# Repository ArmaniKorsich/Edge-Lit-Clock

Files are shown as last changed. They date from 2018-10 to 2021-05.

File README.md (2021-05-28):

# Edge Lit Clock

An Atmega328p powered clock using acryllic panels and ws2812b addressable LEDs as displays.
#
Device View
Front Render

## CAD

All drawings created in Inventor 2016.

The clock consists of 5 seperate displays chained together, with:
* 3
* 10
* 6
* 10
* 6*

panels each. Each panel has a number from 0-9 etched in the following order:  
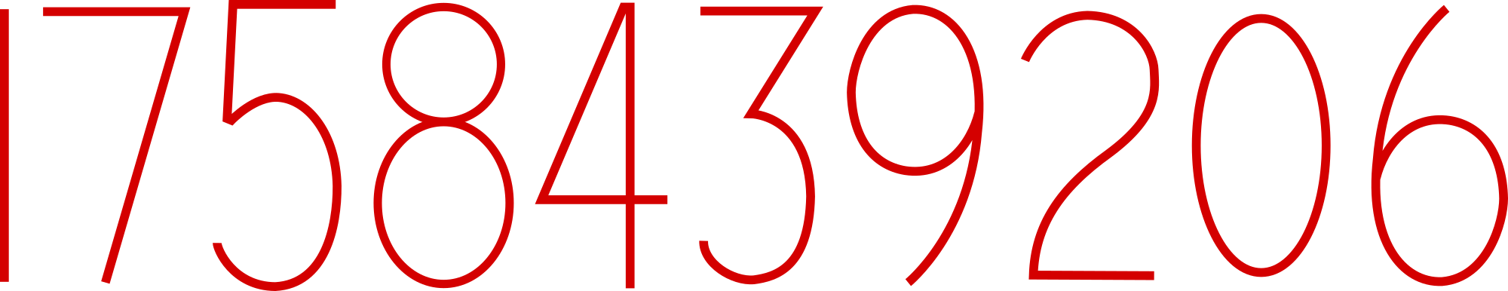
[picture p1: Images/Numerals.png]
Numerals


The off order resembles the old Nixie tube number ordering meant to maximize visiblity of all the digits.

\* *The last display has various symbols instead:*  
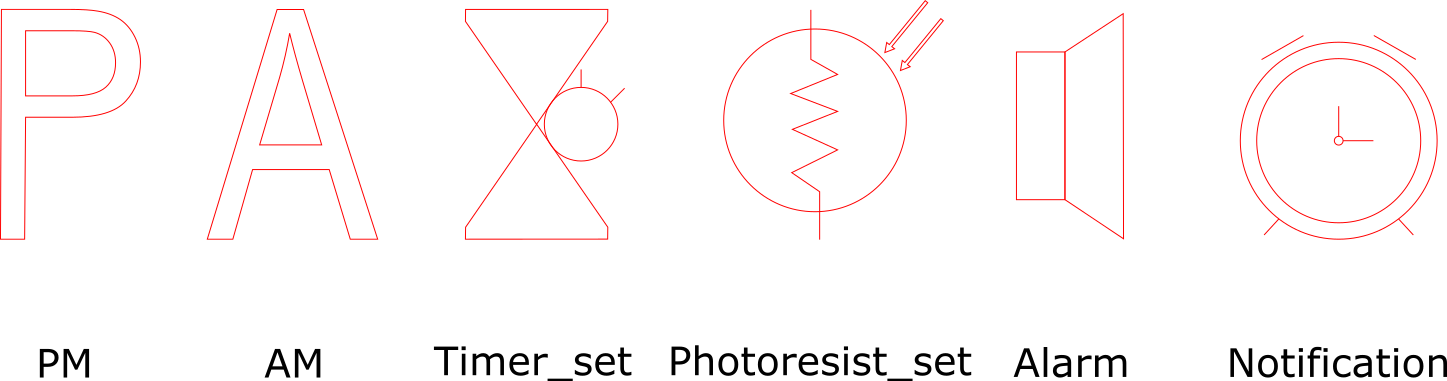
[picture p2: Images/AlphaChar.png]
alpha Symbols


## Electronics

The Atmega328p drives the WS2812B leds using the eLite and FastLED libraries.

The Atmega328p reads time from a DS32321 RTC.  

To protect time information against power outages, I selected a DS3231 which accepts backup battery voltage on PIN14 in the event that VCC cuts out.

All circuit boards were constructed on 2 layer PCBs.
The circuit boards were manufactured by JLCPCB and designed using Autodesk Eagle.

Circuit Board
LED Board

### Input

The device takes 9-40VDC input with at least 2A current capacity. The LM2575-5V buck converter transforms the input to 5V with a 3A limit.

The average current draw of the Edge Lit CLock is ~350 mA with an average of 16 WS2812B activated at any moment.

### Operation

To turn the device on, set the 'POWERTOGGLE' piano switch on the bottom right of the PCB to the 'DOWN' position.

To turn the alarm on, set the 'ALARMTOGGLE' piano switch to the 'DOWN' position.

The three potentiometers on the device control the RED, GREEN, and BLUE color channels of the LEDs.

Pressing the Photoresist_Set button will toggle tracking ambient brightness. When set, the device will lower the brightness of its LEDs to 20% in a fully dark room.

### Setting a Timer

To set a timer, press the TIMER+ or TIMER- button until the device displays the appropriate countdown time.

To start the timer, pres the TIMER_SET button. The device will begin counting down from the set time.

For countdowns over 30 minutes, the device will display hours on the 2 left displays, and minutes on the 2 right displays.

When the countdown reaches <30 minutes, the device will display minutes on the 2 left displays, and seconds on the 2 right displays.

When the countdown reaches 0 seconds, a buzzer will beep.

To disable the buzzing, press the SNOOZE button or restart the device.

## Schematics

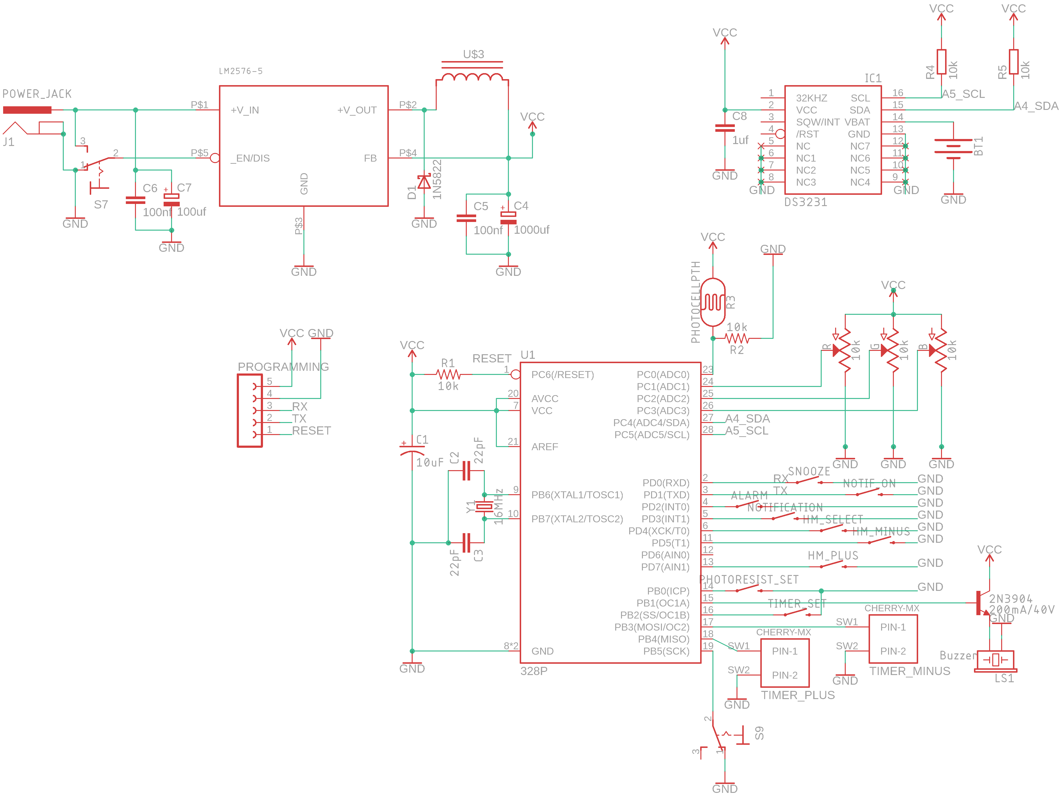
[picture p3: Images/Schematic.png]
Front Render


## Source

This project takes advantage of Arduino's public library system, using 
stdio, FastLED ResponsiveAnalaogRead, EEPROM, Wire, RTCLib
and the provided eLite library for controlling the displays.

ResponsiveAnalogRead: Provides fast and mathematically continuous input values. Minimizes noise in low-cost potentiometers.

stdio: Optional, provides useful debugging information in Arduino IDE.

FastLED: A solution to controlling a large quantity of LEDs rapidly and arbitrarily.

RTClib: Interfaces with the DS3231 Real Time Clock, functions for timekeeping.  

## eLite Library

The eLite library represents the bulk of the content of this project, the clock and physical shape of the project are an example applying this library as my entry to Eisenhower Senior High School's 'Yearly Engineering and Innovation Design Scholarship.'    

`uint8_t defineChain(uint8_t numDisplays,...);`. 
> Inputs(NumDisplays): Number of chained displays in the system.    
> return(chainLength): returns the number of displays in the system.

`void defineLedPerPanel(uint8_t led,...);`. 
> Inputs(led): How many displays there are  
> Inputs(,...): The number of leds per panel in a display, seperated by commas.  
> Tells the system how many LEDs each display has. Useful with physically large plexiglass panels that need more lighting.  
> For a system with 5 displays and 2 leds per panel on each display:  
`void defineLedPerPanel(5, 2, 2, 2, 2, 2)`. 

`void setStandardOrder(uint8_t displayToConfigure);`. 
> inputs(displayToConfigure): Which display to configure. 
> Resets the numercal order of panels in a given display to 0, 1, 2, ... , n. 

`void redefinePanelOrder(uint8_t displayToConfigure, uint8_t quantityPanels,...);`. 
> Inputs(displayToConfigure): Which display to configure   
> Inputs(QuantityPanels): Quantity of panels in display 'DisplayToConfigure'   
> Inputs(,...): The custom order of panels in the display, expects 'QuantityPanels' items, seperated by commas.  

`void drawPanel(uint8_t r, uint8_t g, uint8_t b, uint8_t displayCount, int panelToDraw);`. 
> Inputs(R, G, B): 8-bit integer (0-255), sets the primary color of the displays.     
> Inputs(displayCount): Which display to draw to.  
> Inputs(panelToDraw): The panel to activate in color ##RRGGBB   

`void drawChain(uint8_t r, uint8_t g, uint8_t b, uint8_t lengthOfChain,...);`. 
> Inputs(R, G< B): 8-bit integer (0-255), sets the primary color of the displays.  
> Inputs(lengthOfChain): Number of displays to activate in the chain (0-indexed).  
> inputs(,...): The panel number to activate in each display, seperated by commas.   

`void cycleDisplays(int delayTime, int acceleration, bool direc, uint8_t r, uint8_t g, uint8_t b, uint8_t qtyToCycle,...);`. 
> Inputs(delayTime): Pause between advancing the panels (mS).  
> Inputs(acceleration): Time to decrese delayTime by after each iteration. (mS).  
> Inputs(direc): Cycles forwards (1) or backwards (0).   
> Inputs(R, G, B): 8-bit integer (0-255), sets the primary color of the displays.   
> Inputs(qtyToCycle): Number of displays in the chain to cycle through.   
> Inputs(,...): The index of the displays you wish to cycle through.  
> In a chain of 5 displays, if we wish to cycle the 1st, 3rd, and 4th display:  
`void cycleDisplays(delay, acceleration, forward, R, G, B, 3, 0, 2, 3)`.

`void clearDisplay(uint8_t displayToClear);`
> Inputs(displayToClear): Which display to clear, all panels will be deactivated.  

`void clearChain();`
> Turns off all LEDs in the system, clears all displays.

`uint8_t setChainBrightness(uint8_t brightness);`
> Inputs(brightness): 8-bit integer (0-255), sets the overall opacity (brightness) of the LEDs in FastLED.
> return(brightnessLevel): returns the brightness of the LEDs.

`void randomizeDisplays(int delayTime, int acceleration, int iterations, uint8_t r, uint8_t g, uint8_t b, uint8_t qtyToRandomize, ...);`
> Inputs(delayTime): Pause between iterations in milliseconds (mS).    
> Inputs(acceleration): Time to decrease delayTime by after each iteration. (mS).   
> Inputs(iterations): How many times to activate a random panel on the given displays.    
> Inputs(R, G, B): 8-bit integer (0-255), sets the primary color of the displays.   
> Inputs(qtyToRandomize): Number of displays in the chain to randomize.  
> Inputs(,...): The index of the displays you wish to randomize.  
> If iterations is 1, delay and acceleration aren't important, as the given displays will simply output a random panel. Otherwise, this function provides a simple animation to your chain.

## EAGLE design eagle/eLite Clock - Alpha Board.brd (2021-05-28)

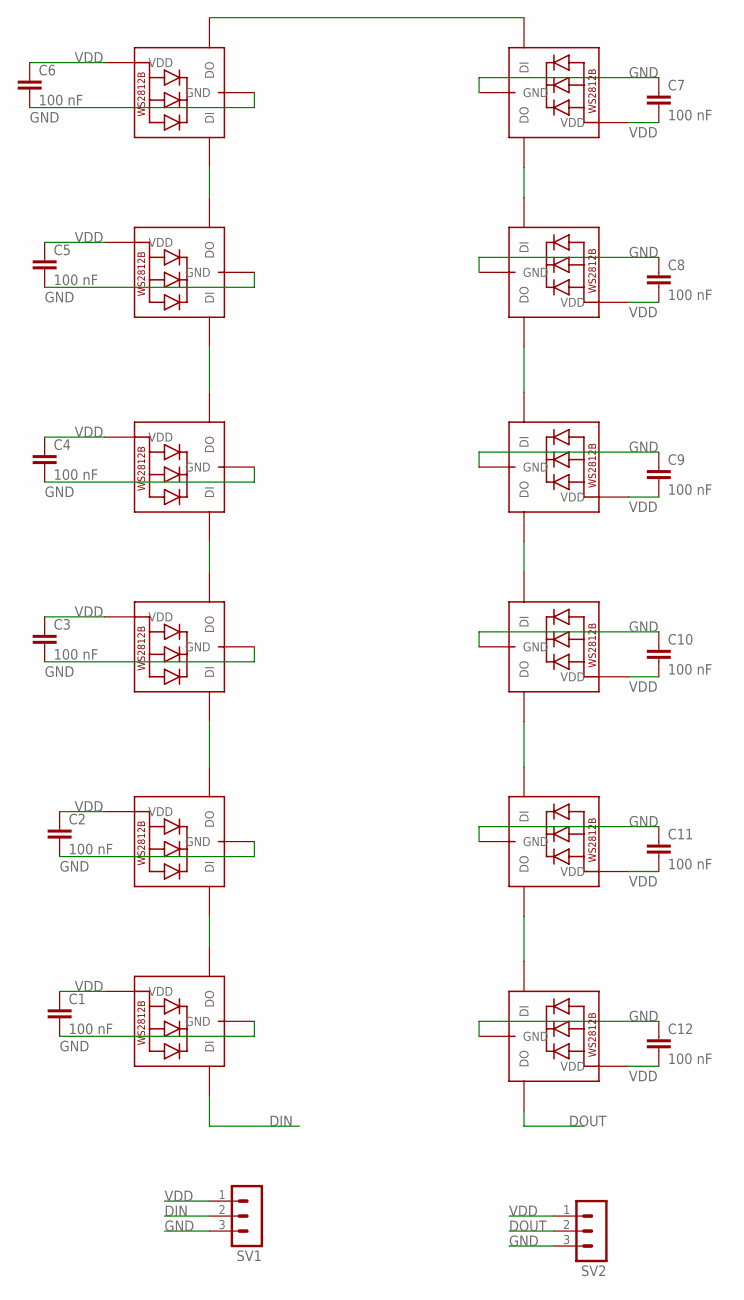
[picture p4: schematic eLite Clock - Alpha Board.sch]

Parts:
C1, C2, C3, C4, C5, C6, C7, C8, C9, C10, C11, C12: 100 nF; C025-025X050
LED1, LED2, LED3, LED4, LED5, LED6, LED7, LED8, LED9, LED10, LED11, LED12: WS2812B_5050W; WS2812B-WIDE
SV1, SV2: MA03-1

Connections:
DIN: LED1.4-DIN (DI), SV1.2
DOUT: LED12.2-DOUT (DO), SV2.2
GND: C1.2, C2.2, C3.2, C4.2, C5.2, C6.2, C7.1, C8.1, C9.1, C10.1, C11.1, C12.1, LED1.3-GND (GND), LED2.3-GND (GND), LED3.3-GND (GND), LED4.3-GND (GND), LED5.3-GND (GND), LED6.3-GND (GND), LED7.3-GND (GND), LED8.3-GND (GND), LED9.3-GND (GND), LED10.3-GND (GND), LED11.3-GND (GND), LED12.3-GND (GND), SV1.3, SV2.3
unnamed: LED1.2-DOUT (DO), LED2.4-DIN (DI)
unnamed: LED2.2-DOUT (DO), LED3.4-DIN (DI)
unnamed: LED3.2-DOUT (DO), LED4.4-DIN (DI)
unnamed: LED4.2-DOUT (DO), LED5.4-DIN (DI)
unnamed: LED5.2-DOUT (DO), LED6.4-DIN (DI)
unnamed: LED6.2-DOUT (DO), LED7.4-DIN (DI)
unnamed: LED7.2-DOUT (DO), LED8.4-DIN (DI)
unnamed: LED8.2-DOUT (DO), LED9.4-DIN (DI)
unnamed: LED9.2-DOUT (DO), LED10.4-DIN (DI)
unnamed: LED10.2-DOUT (DO), LED11.4-DIN (DI)
unnamed: LED11.2-DOUT (DO), LED12.4-DIN (DI)
VDD: C1.1, C2.1, C3.1, C4.1, C5.1, C6.1, C7.2, C8.2, C9.2, C10.2, C11.2, C12.2, LED1.1-VDD (VDD), LED2.1-VDD (VDD), LED3.1-VDD (VDD), LED4.1-VDD (VDD), LED5.1-VDD (VDD), LED6.1-VDD (VDD), LED7.1-VDD (VDD), LED8.1-VDD (VDD), LED9.1-VDD (VDD), LED10.1-VDD (VDD), LED11.1-VDD (VDD), LED12.1-VDD (VDD), SV1.1, SV2.1

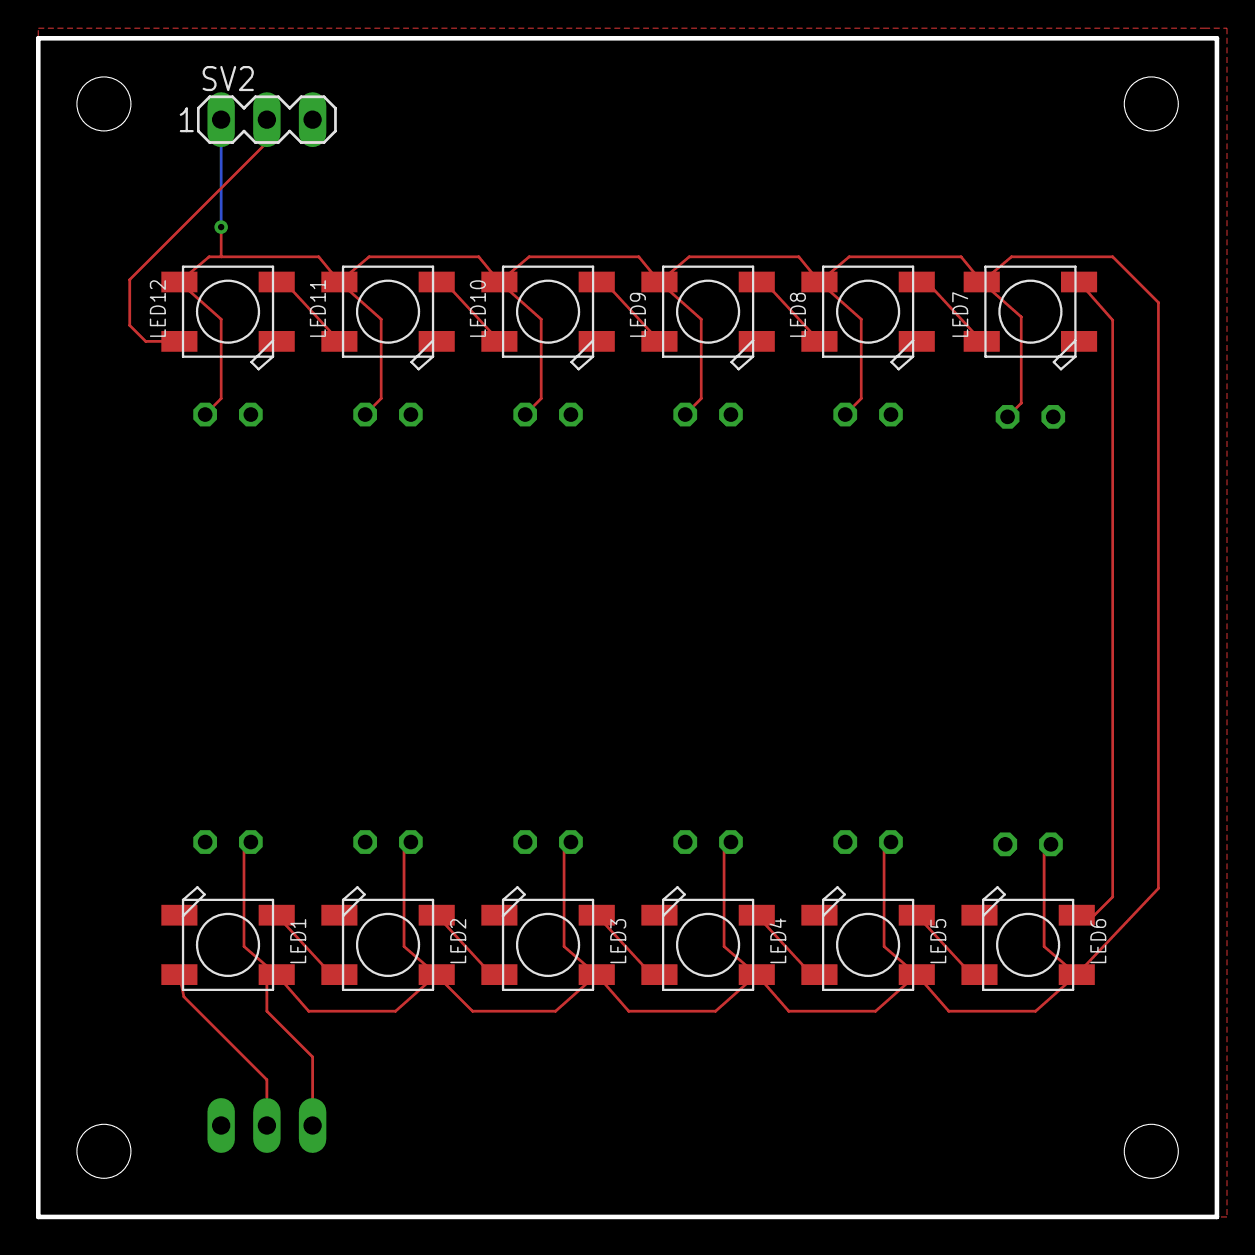
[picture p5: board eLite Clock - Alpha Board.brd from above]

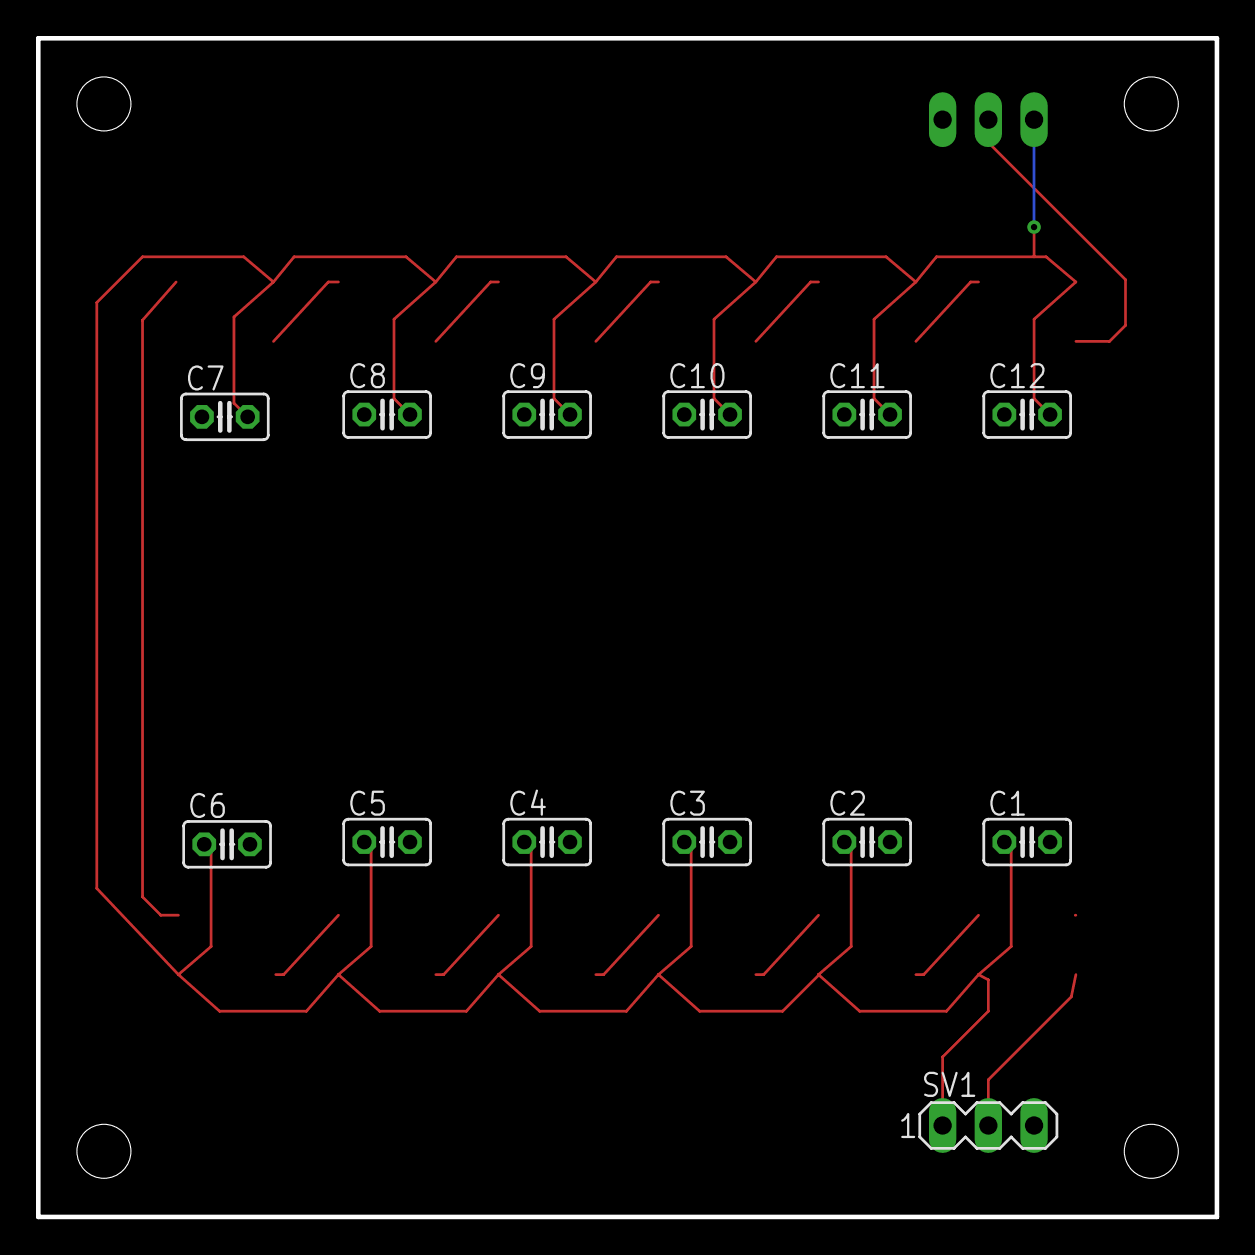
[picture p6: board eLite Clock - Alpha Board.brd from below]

Board: 2 copper layers, 65.5 x 65.5 mm, 26 parts (13 on the bottom side), 15 nets.

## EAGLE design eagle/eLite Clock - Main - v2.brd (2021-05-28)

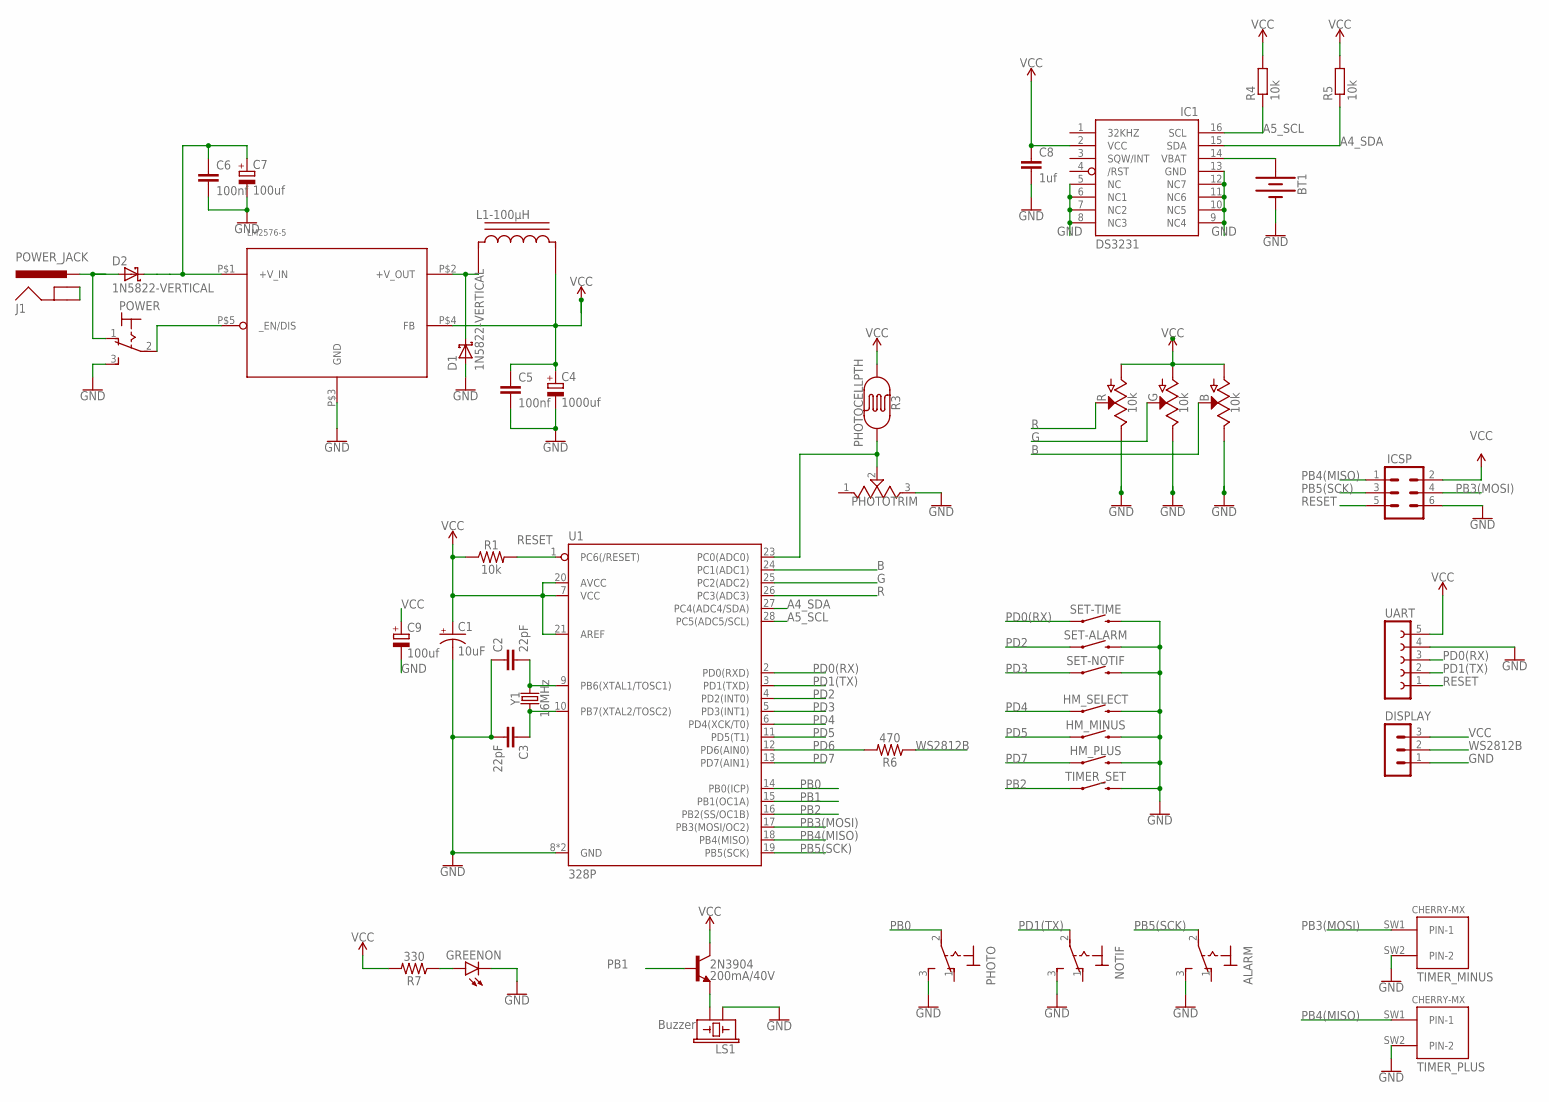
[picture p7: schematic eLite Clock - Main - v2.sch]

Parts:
2N3904: 200mA/40V; TO-92
ALARM: 320-916
B: 10k; SINGLE_GANK_POTENTIOMETER
BT1: BATTERY-20MM_PTH; BATTCOM_20MM_PTH
C1: 10uF; CPOL-RADIAL-2.5MM-5MM
C2, C3: 22pF; CAP-PTH-2.54
C4: 1000uf; E5-13
C5, C6: 100nf; C025-025X050
C7: 100uf; E2,5-5
C8: 1uf; C025-025X050
C9: 100uf; E3,5-10
D1, D2: 1N5822-VERTICAL; DIODE-VERTICAL
DISPLAY: MA03-1
G: 10k; SINGLE_GANK_POTENTIOMETER
GREENON: LED5MM
HM_MINUS: MOMENTARY-SWITCH-SPST-PTH-6.0MM; TACTILE_SWITCH_PTH_6.0MM
HM_PLUS: MOMENTARY-SWITCH-SPST-PTH-6.0MM; TACTILE_SWITCH_PTH_6.0MM
HM_SELECT: MOMENTARY-SWITCH-SPST-PTH-6.0MM; TACTILE_SWITCH_PTH_6.0MM
IC1: DS3231/SO; SO16W
ICSP: MA03-2
J1: POWER_JACK; POWER_JACK_PTH
L1-100µH: T37_INDUCTOR
LM2576-5: LM2576-T05A; TO-220-5_IN-LINE
LS1: Buzzer; BUZZER-12MM
NOTIF: 320-916
PHOTO: 320-916
PHOTOTRIM: 3306F-1-203; TRIM_3306F-1-203
POWER: 320-916
R: 10k; SINGLE_GANK_POTENTIOMETER
R1: 10k; AXIAL-0.3
R3: PHOTOCELLPTH; PHOTOCELL
R4, R5: 10k; 0207/7
R6: 470; AXIAL-0.3
R7: 330; AXIAL-0.3
SET-ALARM: MOMENTARY-SWITCH-SPST-PTH-6.0MM; TACTILE_SWITCH_PTH_6.0MM
SET-NOTIF: MOMENTARY-SWITCH-SPST-PTH-6.0MM; TACTILE_SWITCH_PTH_6.0MM
SET-TIME: MOMENTARY-SWITCH-SPST-PTH-6.0MM; TACTILE_SWITCH_PTH_6.0MM
TIMER_MINUS: TIMER_PLUS; CHERRY-MX
TIMER_PLUS: TIMER_MINUS; CHERRY-MX
TIMER_SET: MOMENTARY-SWITCH-SPST-PTH-6.0MM; TACTILE_SWITCH_PTH_6.0MM
U1: 328P; DIP28
UART: FE05-1
Y1: 16MHz; HC49US

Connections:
A4_SDA: IC1.15 (SDA), R5.1, U1.27 (PC4(ADC4/SDA))
A5_SCL: IC1.16 (SCL), R4.1, U1.28 (PC5(ADC5/SCL))
B: B.P$2, U1.24 (PC1(ADC1))
G: G.P$2, U1.25 (PC2(ADC2))
GND: ALARM.3 (S), B.P$1, BT1.2 (-), C1.2 (-), C2.1, C3.2, C4.-, C5.2, C6.2, C7.-, C8.2, C9.-, D1.ANODE (A), DISPLAY.1, G.P$1, GREENON.K (C), HM_MINUS.3 (2), HM_PLUS.3 (2), HM_SELECT.3 (2), IC1.5 (NC), IC1.6 (NC1), IC1.7 (NC2), IC1.8 (NC3), IC1.9 (NC4), IC1.10 (NC5), IC1.11 (NC6), IC1.12 (NC7), IC1.13 (GND), ICSP.6, LM2576-5.P$3 (GND), LS1.+ (1), NOTIF.3 (S), PHOTO.3 (S), PHOTOTRIM.3 (CW), POWER.3 (S), R.P$1, SET-ALARM.3 (2), SET-NOTIF.3 (2), SET-TIME.3 (2), TIMER_MINUS.SW2 (PIN-2), TIMER_PLUS.SW2 (PIN-2), TIMER_SET.3 (2), U1.8 (GND), U1.22 (GND), UART.4
unnamed: J1.GND, J1.GNDBREAK
unnamed: C2.2, U1.9 (PB6(XTAL1/TOSC1)), Y1.2
unnamed: C3.1, U1.10 (PB7(XTAL2/TOSC2)), Y1.1
unnamed: GREENON.A, R7.P$1 (1)
unnamed: PHOTOTRIM.2 (W), R3.2, U1.23 (PC0(ADC0))
unnamed: D2.ANODE (A), J1.PWR, POWER.1 (O)
unnamed: LM2576-5.P$5 (_EN/DIS), POWER.2
unnamed: 2N3904.1 (E), LS1.- (2)
unnamed: D1.CATHODE (C), L1-100µH.CB, LM2576-5.P$2 (+V_OUT)
unnamed: C6.1, C7.+, D2.CATHODE (C), LM2576-5.P$1 (+V_IN)
unnamed: BT1.1 (+), IC1.14 (VBAT)
PB0: PHOTO.2, U1.14 (PB0(ICP))
PB1: 2N3904.2 (B), U1.15 (PB1(OC1A))
PB2: TIMER_SET.1, U1.16 (PB2(SS/OC1B))
PB3(MOSI): ICSP.4, TIMER_MINUS.SW1 (PIN-1), U1.17 (PB3(MOSI/OC2))
PB4(MISO): ICSP.1, TIMER_PLUS.SW1 (PIN-1), U1.18 (PB4(MISO))
PB5(SCK): ALARM.2, ICSP.3, U1.19 (PB5(SCK))
PD0(RX): SET-TIME.1, U1.2 (PD0(RXD)), UART.3
PD1(TX): NOTIF.2, U1.3 (PD1(TXD)), UART.2
PD2: SET-ALARM.1, U1.4 (PD2(INT0))
PD3: SET-NOTIF.1, U1.5 (PD3(INT1))
PD4: HM_SELECT.1, U1.6 (PD4(XCK/T0))
PD5: HM_MINUS.1, U1.11 (PD5(T1))
PD6: R6.P$2 (2), U1.12 (PD6(AIN0))
PD7: HM_PLUS.1, U1.13 (PD7(AIN1))
R: R.P$2, U1.26 (PC3(ADC3))
RESET: ICSP.5, R1.P$2 (2), U1.1 (PC6(/RESET)), UART.1
VCC: 2N3904.3 (C), B.P$3, C1.1 (+), C4.+, C5.1, C8.1, C9.+, DISPLAY.3, G.P$3, IC1.2 (VCC), ICSP.2, L1-100µH.CA, LM2576-5.P$4 (FB), R.P$3, R1.P$1 (1), R3.1, R4.2, R5.2, R7.P$2 (2), U1.7 (VCC), U1.20 (AVCC), U1.21 (AREF), UART.5
WS2812B: DISPLAY.2, R6.P$1 (1)

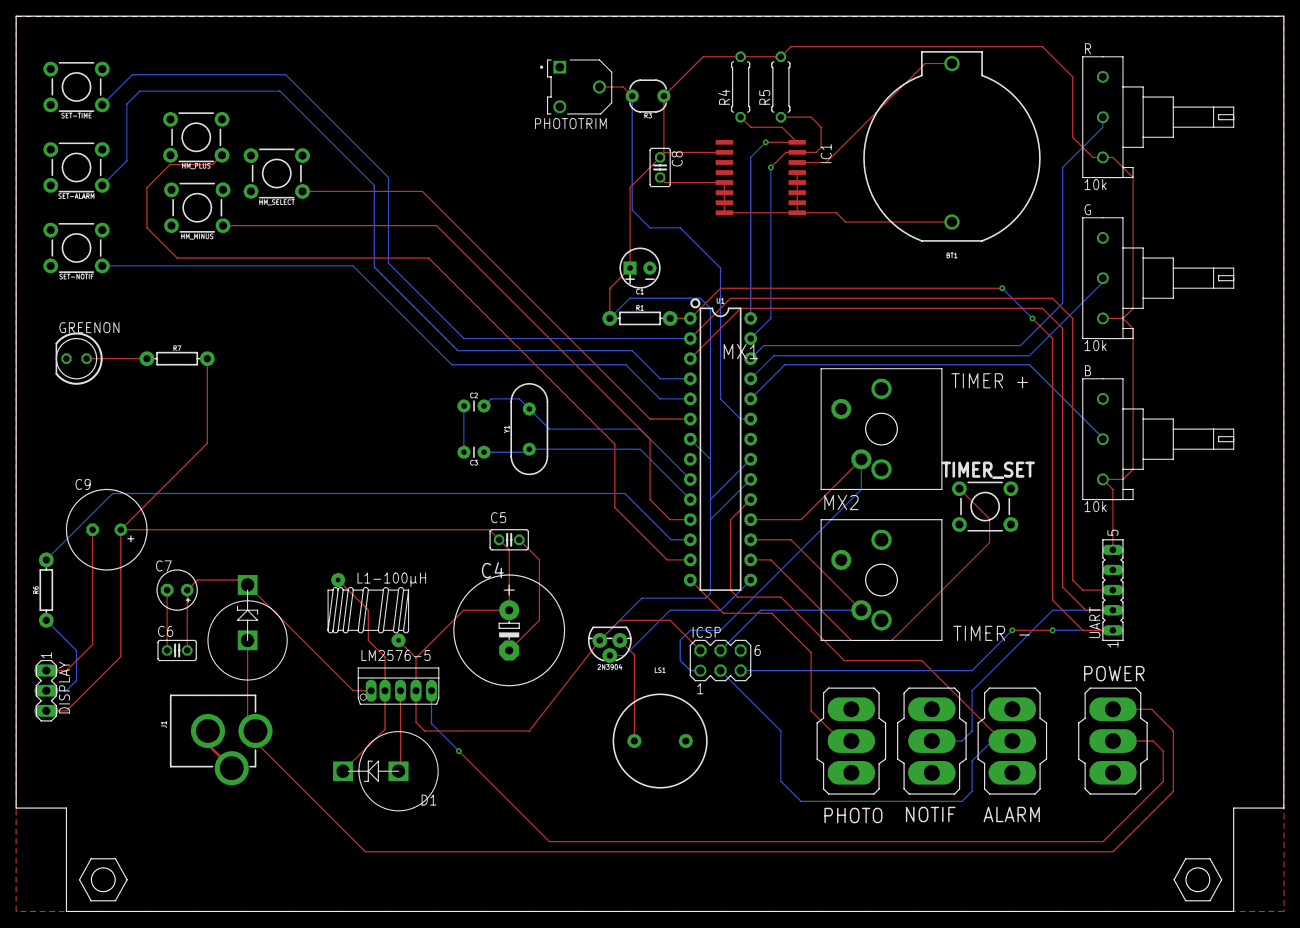
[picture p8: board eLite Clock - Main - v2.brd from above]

Board: 2 copper layers, 160.0 x 113.0 mm, 47 parts (0 on the bottom side), 34 nets.

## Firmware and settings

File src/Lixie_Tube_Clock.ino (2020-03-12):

#include <ResponsiveAnalogRead.h>
#include <eLite.h>
#include <EEPROM.h>
#include <Wire.h>
#include "RTClib.h"
RTC_DS3231 rtc;
uint8_t tSecond;
uint8_t tMinute;
uint8_t tHour;

////Color dials/potentiometers
#define redDial A3 //switched pins for red and blue, easier on the Eagle schematic
#define greenDial A2
#define blueDial A1

ResponsiveAnalogRead redInput(redDial, true);
ResponsiveAnalogRead greenInput(greenDial, true);
ResponsiveAnalogRead blueInput(blueDial, true);

#define stripPin 6
#define stripLength 70
#define displayQuantity 5
eLite eLite(stripPin, stripLength, false);


byte debounceTime = 50;

byte r = 255;
byte g = 255;
byte b = 255;

////Alarm-Time
typedef struct { //declaring a struct which can house the time to ring the alarm (or a notification of the time. [Clock beeps on the hour like a cookoo clock.])
  byte alarmHour = 1; //I had to declare my own struct for the record keeping because the alarm structs used in the RTC library provide inaccurate results when queried in succesion.
  byte alarmMin = 0; //seconds isn't needed, the alarms will only beep at the 0 second mark of the hour/minute which can be wrought from the RTC library.
  boolean state = true;
  boolean beenRung = false;
} alarmTime_type;
alarmTime_type alarmTime[2];

boolean dst;




//Alarm button pins
#define alarmButton 2 //quick press to display time / silence alarm. Long press [~2500 ms] to enter alarm editing mode.
#define notificationButton 3 //same use as alarmButton
#define notifOnBut 0
#define snoozeBut 1
#define alarmOnBut 13


boolean alarmEditMode = false;
boolean alarmToDrawInfo = false;
short alarmEditThreshold = 1500; //milliseconds
boolean alarmToBuzz = false;
unsigned long alarmToBuzzStartTime;
unsigned long alarmFirstBeepTime;
bool alarmBuzzerTimeUndefined = false;
bool toSnooze = false;
bool snoozeDown = true;
unsigned long snoozeStartTime;

boolean timerToBuzz = false;
unsigned long timerToBuzzStartTime;
unsigned long timerFirstBeepTime;
bool timerBuzzerTimeUndefined = false;
boolean notifToBuzz = false;
unsigned long notifToBuzzStartTime;
bool notifBuzzerTimeUndefined = false;
uint8_t notifBeepCount = 0;
boolean notifDown = true;

#define hmBut 4 //switches between allowing you to edit the hour, or the minute.
boolean hmMode;
uint8_t scrollRate = 250;
uint8_t timerScrollRate = 63;
#define hmMinusBut 5 //back 1 hour/min
#define hmPlusBut 7 //forwawrd 1 hour/min

boolean tfMode = false;

//Photoresistor
#define photoBut 8
boolean photoDown = true;
boolean photoOn = true;
boolean photoChanged = false;
//short photoBrightness;
short photoThreshold = 40; //In a range of 1-1024
//short averageBrightness = 64;
//short darkBrightness = 16;
#define photoresistor A0

//Buzzer
#define buzzer 9 //This is a PWM pin on the Atmega328, allows for different tones

//Timer buttons
#define timerSetBut 10
#define timerMinusBut 11
#define timerPlusBut 12
boolean timerCounting = false;
boolean timerSetDown = true;

uint8_t timerHour = 0; //I had to do hour / minute and fancy logic with this because writing it as simply 'how many minutes there are in the timer' and using that to derive time in hours would requrie 8 EEPROM bytes. [1799 minutes inside of 29 hours, 59 minutes.]
uint8_t timerMinute = 0;                                                                                                         
uint8_t timerSecond = 0; //Gets put into use when timer drops below 1 minute / 60 seconds. At which point it is displayed on the edge lit panels.
uint8_t timerCheckSecond = 0;
uint8_t timerStartSecond;
bool timerFirstTick = false;
#define longHoldThreshold 500 //how long to wait before each incrementation of the timer value when holding the timer buttons
#define longHoldIncrementValue 5
#define extraLongHoldIncrementValue 10

void setup() {
  ////////////////////////////////////////////////////////////////////////////////////////////////////////////////
  // put your setup code here, to run once:
  eLite.defineChain(displayQuantity, 2, 9, 5, 9, 5); //There exists #displayQuantity displays [5] with zero-indexed panel count of 2, 9, 5, 9, and 5 respectively.
  eLite.defineLedPerPanel(displayQuantity, 2, 2, 2, 2, 2); //Each panel in the first display has 2 leds, and each panel in the second display has 2 leds, etc.
  eLite.redefinePanelOrder(1, 3, 1, 2, 0); //display #1 has 3 panels. In the order: 1, 2, 0
  eLite.redefinePanelOrder(2, 10, 1, 7, 5, 8, 4, 3, 9, 2, 0, 6);
  eLite.redefinePanelOrder(3, 6, 1, 5, 4, 3, 2, 0);
  eLite.redefinePanelOrder(4, 10, 1, 7, 5, 8, 4, 3, 9, 2, 0, 6);

  r = redInput.getValue(); //Updates the colors on first launch. otherwise each pot has to be turned on startup before active color is seen 
  g = greenInput.getValue();
  b = blueInput.getValue();
  
  eLite.clearChain();
  
  //Serial.begin(9600);
  
  //delay(3000);
  
  pinMode(alarmButton, INPUT_PULLUP);
  pinMode(alarmOnBut, INPUT_PULLUP);
  pinMode(notificationButton, INPUT_PULLUP);
  pinMode(notifOnBut, INPUT_PULLUP);
  pinMode(snoozeBut, INPUT_PULLUP);
  pinMode(hmBut, INPUT_PULLUP);
  pinMode(hmMinusBut, INPUT_PULLUP);
  pinMode(hmPlusBut, INPUT_PULLUP);

  pinMode(photoBut, INPUT_PULLUP);
  pinMode(photoresistor, INPUT);
  pinMode(buzzer, OUTPUT);

  pinMode(timerSetBut, INPUT_PULLUP);
  pinMode(timerMinusBut, INPUT_PULLUP);
  pinMode(timerPlusBut, INPUT_PULLUP);

  if (! rtc.begin()) {
    Serial.println("Couldn't find RTC");
    while (1);
  }

  if (rtc.lostPower()) {
    Serial.println("RTC lost power");
    rtc.adjust(DateTime(F(__DATE__), F(__TIME__)));
    rtc.adjust(DateTime(rtc.now().unixtime() + 17));
    //rtc.adjust(DateTime(F(__DATE__), F(__TIME__)));
  }
  //rtc.adjust(DateTime(F(__DATE__), F(__TIME__)));
  //rtc.adjust(DateTime(rtc.now().unixtime() + 17));
  tSecond = 255; //Ensures the comparsion of these numbers against time succeeds because time will never be '255'
  tMinute = 255;
  tHour = 255;

  //Sets the LEDS for information display
  drawInfo();

  //EEPROM for whether or not daylight savings is on.
  if (EEPROM.read(9) != 0 && EEPROM.read(9) != 1) {
    EEPROM.write(9, 1); dst = 1; //Daylight savings is on by default. Doesn't matter because the script checks to turn it back off or keep it on later.
  } else { dst = EEPROM.read(9); }
  //If the alarm memory has never been set before, reset it.
  if (EEPROM.read(0) > 24 or EEPROM.read(2) > 24 or EEPROM.read(1) > 59 or EEPROM.read(3) > 59) {
  EEPROM.write(0, 24); EEPROM.write(1, 0); EEPROM.write(2, 24); EEPROM.write(3, 0); }
  //Writes alarm times and notification times from memory
  alarmTime[0].alarmHour = EEPROM.read(0);
  alarmTime[0].alarmMin = EEPROM.read(1);
  alarmTime[1].alarmHour = EEPROM.read(2);
  alarmTime[1].alarmMin = EEPROM.read(3);

  if (EEPROM.read(8) != 0 && EEPROM.read(8) != 1) {
    EEPROM.write(8, 0);
    alarmTime[1].state = EEPROM.read(8);
  } else {
    alarmTime[1].state = EEPROM.read(8);
  }
  //Writes various Setting states from memory
  //photoresistor memory
  if (EEPROM.read(5) == 255) { EEPROM.write(5, 0); }
  else { photoOn = EEPROM.read(5); }

  
  

  //timer Memory
  if (EEPROM.read(6) > 24 or EEPROM.read(7) > 59) { EEPROM.write(6, 0); EEPROM.write(7, 0); }
  timerHour = EEPROM.read(6);
  timerMinute = EEPROM.read(7);

}

void displayAlarmTime(uint8_t toEdit) {
  uint8_t alarmTimeHour;
  eLite.clearDisplay(4);
  if (!tfMode) {
    alarmTimeHour = alarmTime[toEdit].alarmHour;
    if (alarmTimeHour > 12) {
      alarmTimeHour -= 12;
    }
    if ((alarmTime[toEdit].alarmHour >=1 and alarmTime[toEdit].alarmHour <= 11) or alarmTime[toEdit].alarmHour == 24) { eLite.drawPanel(r, g, b, 4, 1); } //Draws the AM
    else if (alarmTime[toEdit].alarmHour >= 12 and alarmTime[toEdit].alarmHour <= 23) { eLite.drawPanel(r, g, b, 4, 0); }
  if (toEdit == 1) {
    eLite.drawPanel(r, g, b, 4, 5);    
  } else {
    eLite.drawPanel(r, g, b, 4, 4);
  }
  eLite.clearDisplay(0); eLite.drawPanel(r, g, b, 0, (alarmTimeHour / 10) % 10);
  eLite.clearDisplay(1); eLite.drawPanel(r, g, b, 1, alarmTimeHour % 10);  
  } else {
  eLite.clearDisplay(0); eLite.drawPanel(r, g, b, 0, (alarmTime[toEdit].alarmHour / 10) % 10);
  eLite.clearDisplay(1); eLite.drawPanel(r, g, b, 1, alarmTime[toEdit].alarmHour % 10);
  }
  eLite.clearDisplay(2); eLite.drawPanel(r, g, b, 2, (alarmTime[toEdit].alarmMin / 10) % 10);
  eLite.clearDisplay(3); eLite.drawPanel(r, g, b, 3, alarmTime[toEdit].alarmMin % 10);
  
}
void drawAlarmHour(uint8_t toEdit) {
  uint8_t alarmTimeHour;
  eLite.clearChain(); if (!tfMode) { //converts the 1-24 o'clock of the alarm buttons into 0-12 AM and PM if we're not in 24 hour mode. [tfMode]
  alarmTimeHour = alarmTime[toEdit].alarmHour; 
  if (alarmTimeHour > 12) {
    alarmTimeHour -= 12;
  }
  if ((alarmTime[toEdit].alarmHour >=1 and alarmTime[toEdit].alarmHour <= 11) or alarmTime[toEdit].alarmHour == 24) { eLite.drawPanel(r, g, b, 4, 1); } //Draws the AM
  else if (alarmTime[toEdit].alarmHour >= 12 and alarmTime[toEdit].alarmHour <= 23) { eLite.drawPanel(r, g, b, 4, 0); }
    eLite.drawPanel(r, g, b, 0, (alarmTimeHour / 10) % 10);
    eLite.drawPanel(r, g, b, 1, alarmTimeHour % 10); 
  } else {
    eLite.drawPanel(r, g, b, 0, (alarmTime[toEdit].alarmHour / 10) % 10);
    eLite.drawPanel(r, g, b, 1, alarmTime[toEdit].alarmHour % 10);
  }
}
void drawAlarmMinute(uint8_t toEdit) {
  eLite.clearChain(); if (!tfMode) {
    if ((alarmTime[toEdit].alarmHour >=1 and alarmTime[toEdit].alarmHour <= 11) or alarmTime[toEdit].alarmHour == 24) { eLite.drawPanel(r, g, b, 4, 1); } //Draws the AM
    else if (alarmTime[toEdit].alarmHour >= 12 and alarmTime[toEdit].alarmHour <= 23) { eLite.drawPanel(r, g, b, 4, 0); }
  }
  eLite.drawPanel(r, g, b, 2, (alarmTime[toEdit].alarmMin / 10) % 10);
  eLite.drawPanel(r, g, b, 3, alarmTime[toEdit].alarmMin % 10);
}
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
void loop() {
  if (tSecond != rtc.now().second()) {
    tSecond = rtc.now().second();
    setClockTime();
  } //daylight savings. Going to have to hope that the date logic works can't really test it atm.
  if (rtc.now().dayOfTheWeek() == 0 && rtc.now().month() == 3 && rtc.now().day() >= 8 && rtc.now().hour() >= 2 && dst == 0) {
    dst = 1;
    rtc.adjust(DateTime(rtc.now().unixtime() + 3600)); //Sets clock forward 1 hour.
    EEPROM.write(9, 1);
  }
  if (rtc.now().dayOfTheWeek() == 0 && rtc.now().month() == 11 && rtc.now().day() >= 1 && rtc.now().hour() >= 2 && dst == 1) {
    dst = 0;
    rtc.adjust(DateTime(rtc.now().unixtime() - 3600)); //Sets clock backward 1 hour.
    EEPROM.write(9, 0);
  }

  //Quick and Easy control of the RGB values of the clock.
  redInput.update(); //ResponiveAnalogRead requires this. This removes noise from the dials. Necessary so the ForceClockTime function isn't constantly being called and causing flickering
  greenInput.update();
  blueInput.update();
  
  if (redInput.hasChanged()) { r = redInput.getValue(); forceClockTime(); }//Serial.println("red");}
  if (greenInput.hasChanged()) { g = greenInput.getValue(); forceClockTime(); }// Serial.println("green"); }
  if (blueInput.hasChanged()) { b = blueInput.getValue(); forceClockTime(); }//Serial.println("blue"); }

  if (!digitalRead(alarmButton)) { 
    
    timerToBuzz = false;
    alarmToBuzz = false;
    Serial.println("alarmButton");
    analogWrite(buzzer, 0);
    alarmPressed(alarmButton, 0);
  } //View or edit the alarm time.
  if (!digitalRead(notificationButton)) { alarmPressed(notificationButton, 1);} //View or edit the alarm time.
  
  
  //Allows a photoresistor to dim the click in dark situations. But if the button is pressed, you can switch this feature off. Leaving the clock at your average brightness setting.
  if (!digitalRead(photoBut)) {photoDown = false; delay(debounceTime);}
      if (digitalRead(photoBut) && photoDown == false) {photoDown = true; photoOn = !photoOn; EEPROM.write(5, photoOn);
        if (!photoOn) {
          eLite.setChainBrightness(255);
          EEPROM.write(5, 0);
        }
        forceClockTime();
        if (photoOn) {
          EEPROM.write(5, 1);
          if (analogRead(photoresistor) < photoThreshold) {
            photoChanged = false;
          } else { photoChanged = true; }
          Serial.println("Photoresistor Enabled");
          Serial.println(analogRead(photoresistor));
          //Serial.println(photoBrightness);
          Serial.print("\n"); 
        } else {Serial.println("Photoresistor Disabled\n");
          eLite.setChainBrightness(255);
        }
      }
  if (photoOn) {
    if (analogRead(photoresistor) < photoThreshold) {
      eLite.setChainBrightness(20); 
      if (!photoChanged) {
        //Serial.println("Its set dark!");
        photoChanged = true;
        forceClockTime();
      }
    
   } else { 
      eLite.setChainBrightness(255);
      if (photoChanged) {
        //Serial.println("Its Bright!");
        photoChanged = false;
        forceClockTime();
      }
   }
  }
  
  //A timer functionality.
  if (!digitalRead(timerPlusBut)) {Serial.println("timerPlus"); timerPressed(); drawTimer(); }
  if (!digitalRead(timerMinusBut)) {Serial.println("timerMinus"); timerPressed(); drawTimer(); }
  if (!digitalRead(timerSetBut)) {timerSetDown = false; delay(debounceTime);}
      if (digitalRead(timerSetBut) && timerSetDown == false) {timerSetDown = true; timerPressed(); }
  //Serial.println(analogRead(photoresistor));


  //Alarms
  if (alarmTime[0].state) { //ALARM
    if (tHour == alarmTime[0].alarmHour && tMinute == alarmTime[0].alarmMin && alarmTime[0].beenRung == false) { //requires a flag to be false before the alarm buzzing can be enabled that way it does not keep buzzing if the user turns off the alarm.
      alarmToBuzz = true;
      alarmFirstBeepTime = rtc.now().unixtime(); //In case the millis() number overflows to zero, im referencing unix time. Most other instances can use 
                                     //millis() (such as beep patterns) because if millis() overflows, the pattern will skip one measure. If millis() overflows for this check, the alarm will not turn off
                                     //if no one is there to attend it. The neighbours would not like that. The alarm has to turn off after 20 minutes.
      alarmTime[0].beenRung = true;
      Serial.println("beginning alarm beeping");
      alarmBuzzerTimeUndefined = true;
  }
  } if (tMinute-1 == alarmTime[0].alarmMin && alarmTime[0].beenRung == true) { //Waits 1 minute before letting the flag reset, thus requiring 24 hours to pass before alarm buzzing can be enabled again.
    alarmTime[0].beenRung = false;                                             //This event has to occur [outside of //if(alarmTime[0].state)//] even if the alarm is disabled because the alarms state could potentially be disabled
    Serial.println("resetting alarm variables");                               //before the reset, and then if the alarm is reenabled within 24 hours, the buzzer will not activate because the flags haven't been set.
  }
///////////////
  if (alarmTime[1].state) { //NOTIFICATION
    if (tHour == alarmTime[1].alarmHour && tMinute == alarmTime[1].alarmMin && alarmTime[1].beenRung == false) { //requires a flag to be false before the alarm buzzing can be enabled that way it does not keep buzzing if the user turns off the alarm.
      Serial.println("beginning notif beeping");
      notifBeepCount = 0;
      notifToBuzz = true;
      alarmTime[1].beenRung = true;
      notifBuzzerTimeUndefined = true;
  }
  } if (tMinute-1 == alarmTime[1].alarmMin && alarmTime[1].beenRung == true) {
    Serial.println("reset notif");
    alarmTime[1].beenRung = false;                                             
  }
  //Sets up a pulsing buzzer without using a blocking delay function because of the micronctrollers single thread.
  if (timerToBuzz) {
    if (rtc.now().unixtime() - timerFirstBeepTime >= 90) { //After 90 seconds the timer stops beeping.
      timerToBuzz = false;
      forceClockTime();
      Serial.println("timer will now cease");
    }
    Serial.println("buzz timer");
    if (timerBuzzerTimeUndefined == true) { 
      timerToBuzzStartTime = millis(); 
      timerBuzzerTimeUndefined = false; }
    if ((millis() - timerToBuzzStartTime) >= 1 && (millis() - timerToBuzzStartTime <= 500) ) {
      analogWrite(buzzer, 125);
    }
    if ((millis() - timerToBuzzStartTime) > 500 && (millis() - timerToBuzzStartTime <= 1000) ) {
      analogWrite(buzzer, 0);
    } if ((millis() - timerToBuzzStartTime) > 1000) {
      timerToBuzzStartTime = millis();
    }
  } //Snooze function
  
  if (alarmToBuzz) {
    if (rtc.now().unixtime() - alarmFirstBeepTime >= 1800) { //1800 seconds = 30 minutes. after 30 minutes the alarm will cease beeping.
      
      alarmToBuzz = false;
      forceClockTime();
      Serial.println("alarm will now cease.");
      analogWrite(buzzer, 0);
    }
    if (!digitalRead(snoozeBut)) {snoozeDown = false; delay(debounceTime);}
        if (digitalRead(snoozeBut) && snoozeDown == false) {
          Serial.println("starting snooze");
          snoozeDown = true;
          toSnooze = true;
          snoozeStartTime = millis();
          analogWrite(buzzer, 0);
          forceClockTime();
        }
    if (toSnooze) {
      if (millis() - snoozeStartTime >= 300000) { //5 minutes = 300000
        Serial.println("should continue beeping");
        toSnooze = false;
        alarmBuzzerTimeUndefined = true;
      }
    }
  } 
  if (alarmToBuzz == true && toSnooze == false) {
    Serial.println("atoBuzz");
    if (alarmBuzzerTimeUndefined == true) { alarmToBuzzStartTime = millis(); alarmBuzzerTimeUndefined = false; }
    if ((millis() - alarmToBuzzStartTime) >= 1 && (millis() - alarmToBuzzStartTime) <= 300 ) {
      analogWrite(buzzer, 255);
      eLite.clearChain();
    }
    if ((millis() - alarmToBuzzStartTime) > 300 && (millis() - alarmToBuzzStartTime) <= 600 ) {
      analogWrite(buzzer, 0);
      forceClockTime();
      
    } if ((millis() - alarmToBuzzStartTime) > 600) {
      Serial.println("settting start time");
      alarmToBuzzStartTime = millis();
    }
  }
  if (notifToBuzz) {
    if (notifBeepCount < 2) { //Notification should only beep twice before stopping itself.
      //Serial.println("test1");
      if (notifBuzzerTimeUndefined) { notifToBuzzStartTime = millis(); notifBuzzerTimeUndefined = false;}
      //Serial.println("will buzz notif");
      if (((millis() - notifToBuzzStartTime) >= 1) && (millis() - notifToBuzzStartTime <= 150) ) {
        analogWrite(buzzer, 30);
        //Serial.println("on");
      }
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

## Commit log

2021-05-28 add device view
2021-05-28 add pcb view
2021-05-28 add ledView
2021-05-28 Add files via upload
    This is all the eagle work to generate and view the schematics and circuit boards for this project.

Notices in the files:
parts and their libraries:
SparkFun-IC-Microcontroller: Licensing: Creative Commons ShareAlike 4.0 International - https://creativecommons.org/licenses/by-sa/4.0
